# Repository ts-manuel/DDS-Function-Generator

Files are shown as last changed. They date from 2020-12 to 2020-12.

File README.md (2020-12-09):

# DDS Function Generator
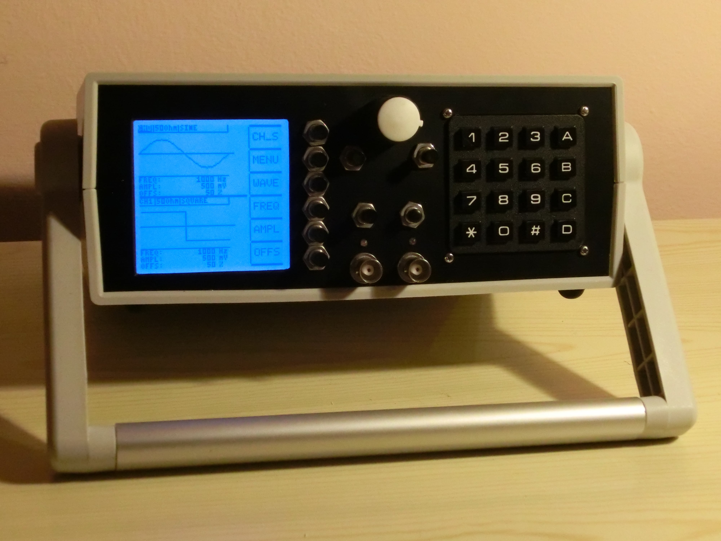
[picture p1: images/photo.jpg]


<!-- TABLE OF CONTENTS -->
<details open="open">
  <summary>Table of Contents</summary>
  <ol>
    <li>
      <a href="#about-the-project">About The Project</a>
    </li>
    <li>
      <a href="#getting-started">Getting Started</a>
      <ul>
        <li><a href="#prerequisites">Prerequisites</a></li>
        <li><a href="#compiling-code-for-the-cpu">Compiling code for the CPU</a></li>
        <li><a href="#how-to-program-the-fpga">How to program the FPGA</a></li>
      </ul>
    </li>
    <li>
        <a href="#theory-of-operation">Theory of Operation</a>
        <ul>
            <li><a href="#block-diagram">Block Diagram</a></li>
            <li><a href="#fpga-internal-structure">FPGA Internal Structure</a></li>
            <li><a href="#dds-core">DDS Core</a></li>
            <li><a href="#wave-generator">Wave Generator</a></li>
        </ul>
    </li>
    <li><a href="#future-improvements">Future Improvements</a></li>
    <li><a href="#references">References</a></li>
    <li><a href="#disclaimer">Disclaimer</a></li>
  </ol>
</details>

<!-- ABOUT THE PROJECT -->
## About The Project
This project is a dual-channel function generator. Waveforms are generated digitally inside an FPGA via DDS ([Direct Digital Synthesis](https://www.analog.com/en/analog-dialogue/articles/all-about-direct-digital-synthesis.html)). The main purpose of this project was to get familiar with FPGAs and at the same time build something useful to have in the lab.

* Frequency DC to 20Mhz
* Power 28 dBm - 6Vrms into 50 Ohms
* Output waveforms: square, triangle, sawtooth, sine, wave file from SD card
* Independent AM and FM modulation on both channels
* Frequency Sweep
* Programmable phase offset between channels

<!-- GETTING STARTED -->
## Getting Started
### Prerequisites
* [Quartus 18.1](https://fpgasoftware.intel.com/18.1/?edition=lite) with `MAX 10 FPGA device support`

### Compiling code for the CPU
* Open Quartus, click on `Tools > Nios II Software Build Tools for Eclipse`
* Select a folder to be used as a workspace (make sure the path has no spaces)
* Click on `File > Import`
* Select `General > Existing Project into Workspace` then click next
* Browse for the folder `fpga/software` select both projects and click finish
* right-click on `DDS_FunctionGen_20Mhz_bsp` than on `Nois II > Generate BSP`
* Now to build the project right-click on `DDS_FunctionGen_20Mhz` than click on `Build Project`
* To generate the FPGA FLASH initialization file, right-click on `DDS_FunctionGen_20Mhz` then click `Make Targets > Build`, select `mem_init_generate` and press `Build`

### How to program the FPGA
* Open the project file `fpga/DDS_FunctionGenerator_20Mhz.qpf` with Quartus
* Press `Compile Design`

<!-- BLOCK DIAGRAM -->
## Theory of Operation
This section gives a basic overview of the main components and how they interact.

### Block Diagram
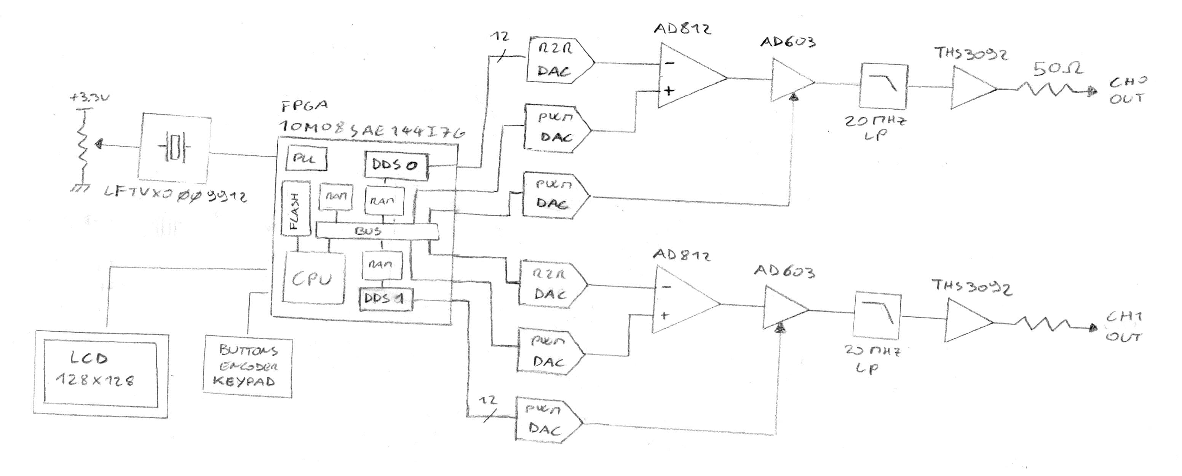
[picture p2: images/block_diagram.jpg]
block diagram

The driver of the show is the FPGA, it's a `10M08SAE144I7G` from the Altera MAX10 Series. MAX10 devices are cool because they have a built-in configuration flash memory and some UFM (User Flash Memory) that can be written when the FPGA is programmed to store non-volatile data. This project uses the UFM to store code for the CPU.\
The clock is provided by a 10Mhz TCXO oscillator, a potentiometer connected to the adj. pin is used to adjust the frequency.\
First, the signal is generated digitally inside the FPGA, then it goes into a 12bit R2R DAC that converts it to an analog voltage. The signal then passes through an inverting op-amp where a DC offset is added. After that, there's a VGA to control the output level. The signal is then filtered by an active op-amp filter before entering the final amplifier.

### FPGA Internal Structure
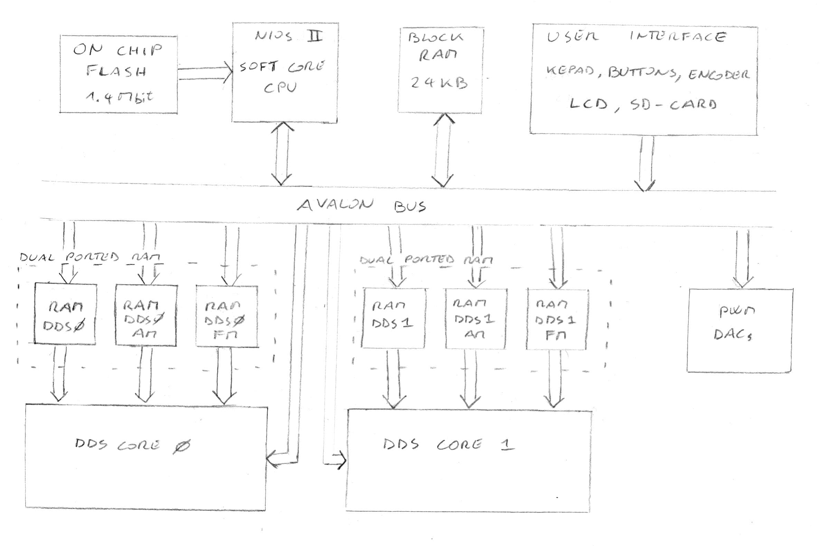
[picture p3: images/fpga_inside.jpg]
FPGA Internal Structure

This block diagram describes the interaction between modules inside the FPGA. All components are memory-mapped on the same bus and are all controlled by the CPU. The CPU is a NIOS II Soft Core provided by Altera, it executes code directly from FLASH. It handles all the user interface stuff like responding to button presses, updating the screen and talking to the SD card.\
The second main module is the DDS Core, there are two of them, one for each channel.
The DDS Core is responsible for the generation of the output waveform. Each DDS Core interfaces whit the CPU through three look-up RAMs and a control bus. Waveform parameters like frequency, modulation depth, etc. are set via the control bus. Waveform shape is controlled by the look-up RAM. The CPU can update the look-up RAM content at any time. When a wave file is played, the CPU loads samples from the SD Card into the proper look-up RAM. The output frequency is set equal to the wave file sample frequency therefore, the DDS Core reads one sample at a time from memory and reconstructs the signal. When half of the samples are consumed an interrupt is triggered and the CPU replaces that half with new data.

### DDS Core
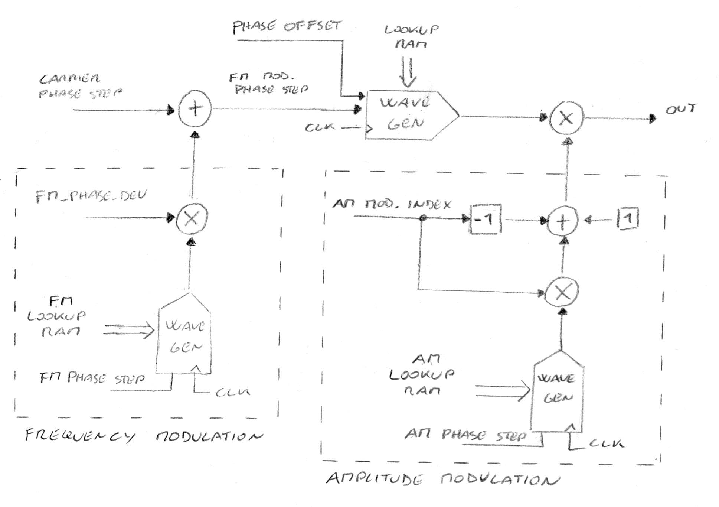
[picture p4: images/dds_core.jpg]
DDS Core

This module is a wrapper around three `Wave Generator` modules. One of them is used to generate the main waveform, the others are for frequency and amplitude modulation. The `CARRIER_PHASE_STEP` input is the frequency of the unmodulated waveform, a signal is added to it to achieve frequency modulation. Amplitude modulation is applied to the signal at the end.

### Wave Generator
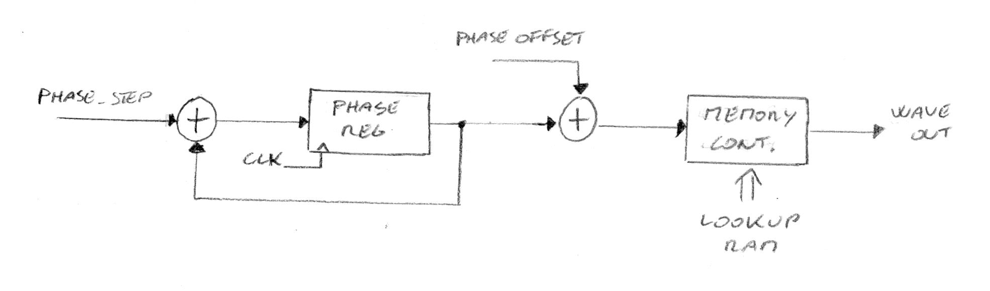
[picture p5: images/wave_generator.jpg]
Wave Generator

This module takes samples from a look-up RAM and outputs a waveform. Frequency is selected with the `PHASE_STEP` input. The `PHASE_OFFSET` input adds a phase offset to the waveform. The memory controller looks at the current phase to generate the appropriate address to index the look-up RAM.

<!-- FUTURE IMPROVEMENTS -->
## Future Improvements
* Add a cache memory between CPU and FLASH. Without that code runs slow and the user interface is not super responsive.
* Upgrade to a bigger FPGA with more UFM. UFM is too small to fit any more code, thus the SD card functions can't be fully implemented.
* Use a proper DAC IC. The R2R DACs are inadequate, even with 0.1% resistors the nonlinearity is too much.

<!-- REFERENCES -->
## References
* [FatFs - Generic FAT Filesystem Module](http://elm-chan.org/fsw/ff/00index_e.html)
* [All About Direct Digital Synthesis - Analog Devices](https://www.analog.com/en/analog-dialogue/articles/all-about-direct-digital-synthesis.html)
* [Fundamentals of Direct Digital Synthesis (DDS) - Analog Devices](https://www.analog.com/media/en/training-seminars/tutorials/MT-085.pdf)

<!-- DISCLAIMER -->
## Disclaimer
The following project is shared "as is", with the sole objective of being useful. The creator of the described piece of hardware and its associated software cannot guarantee its correct functioning under any circumstance. The author of this project will not be held responsible for any material, personal or economic losses to you or any third parties that may arise from using this design. This project will not be used under any circumstances on systems whose responsibility is critical, or from which people's lives depend upon, directly or indirectly.

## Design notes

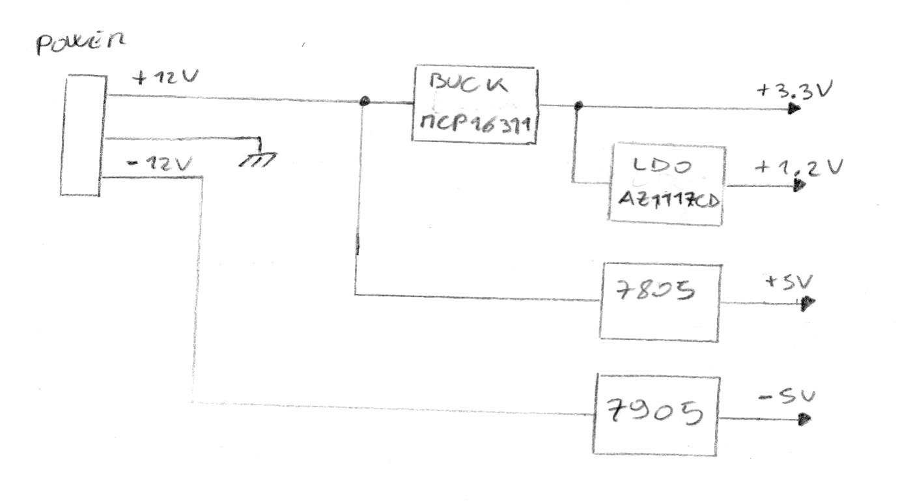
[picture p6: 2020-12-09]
images/power.jpg

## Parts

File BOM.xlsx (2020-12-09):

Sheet: BOM_PartType-FPGA_SignalGenerat
Quantity | Comment | Description | Designator | Footprint | Value |  | Resistance | Capacitance
18 | Vishay 74-293D106X0035C2TE3 | 293D Series 10 uF ±20 % 35 V Surface Mount Standard Molded Tantalum Capacitor | C1, C2, C3, C25, C26, C27, C49, C61, C62, C63, C67,C69, C72, C80, C81, C93, C94, C105 | PCB-uo7hy2lsxdj8f9kxxyxw-1 |  | OK |  | 10 µF
73 | KEMET C0805C104K5RACTU | Capacitor, ceramic, 0.1 uF, +/-10% Tol, 50V, X7R, -55/+125C, 0805, Tin Termination, T&R Paper Tape 7in | C4, C5, C6, C7, C8, C9, C10, C11, C12, C14, C16, C18, C19, C20, C21, C22, C23, C24, C28, C29, C30, C31, C32, C33, C34, C35, C36, C38, C40, C42, C43, C44, C45, C46, C47, C48, C66, C68, C70, C73, C74, C75, C76, C77, C78, C79, C82, C83, C84, C85, C86, C87, C88, C89, C90, C91, C92, C95, C96, C97, C98, C99, C100, C101, C102, C103, C104, C106, C107, C108, C109, C110, C117 | Capacitor 0805 |  | OK |  | 100nF
6 | Kemet C0805C101J5GAC7800 | Multilayer Ceramic Capacitors MLCC - SMD/SMT 50volts 100pF C0G 5% | C13, C15, C17, C37, C39, C41 | CAPC2013X88X50ML20T25 |  | OK |  | 100pF
9 | Kemet C0805C105Z4VACTU | 0805/Case Surface Mount/Pkg 1uf 16-Volt Y5v-Temp Multilayer Ceramic Capacitor | C50, C51, C52, C53, C54, C55, C64, C65, C71 | PCB-s8ugi4gyvlk8r34jcx7t-1 |  | OK |  | 1uF
6 | AVX Interconnect / Elco 08055A4R7CAT2A | CAP CER 4.7PF 50V NP0 0805 | C111, C112, C113, C114, C115, C116 | CAPC2013X71X50LL20T25 |  | OK |  | 4.7pF, 4.7pF, 0.68pF, 4.7pF, 4.7pF, 0.68pF
4 | AVX W3A45C473KAT2A | Cap Ceramic Array 1uF 6.3V JB 20% 1206 SMD 4 Capacitor 85°C Blister Plastic T/R | CN1, CN2, CN3, CN4 | PCB-166aiy90vkqaobkxelpm-1 |  | OK |  | 1uF
1 | LED | Surface Mount LED; Size : 2.0X1.2mm (0805); Color: Green; Lens: Water Clear | D1 | AP2012EC |  | OK
1 | Microchip MCP16311-E/MS | MCP16311 Series 30 Vin 1 A 500 kHz Synchronous Buck Switching Regulator - MSOP-8 | IC1 | PCB-bk1d1h6o78f0n1u0od64-1 |  | OK
1 | BUTTONS | Connector Ejector Header 20 Position 2.54mmThrough Hole | J1 | PCB-2yon6ahruktjsjib9q9l-1 |  | OK
1 | LCD 128x128 | FFC / FPC Board Connector, Easy-On 505110 Series, Surface Mount, Receptacle, 30, Bottom, 0.5 mm | J2 | PCB-vghu3xxueitsn32e31p1-1 |  | OK
1 | LCD BackLight | A2001WR-S-2PSMT | J3 | PCB-pe0trybbrqxd1byjn5yf-1 |  | OK
1 | LED_BTN | 2.54mm (0.1") Pitch SIL Vertical PC Tail Pin Header, 6.1mm mating pin height, gold (hi-temp mould), 6 contacts | J4 | PCB-tb5z704sg1unzd01km8p-1 |  | OK
5 | CH0_OUT | RF Connectors / Coaxial Connectors SMA RA JACK PCB 50 OHM AU | J5 | PCB-3770251-1 |  | OK
1 | EXT_IN | 2.54mm (0.1") Pitch SIL Vertical PC Tail Pin Header, 6.1mm mating pin height, gold (hi-temp mould), 6 contacts | J10 | PCB-tb5z704sg1unzd01km8p-1 |  | OK
1 | SD | 2.54mm (0.1") Pitch SIL Vertical PC Tail Pin Header, 6.1mm mating pin height, gold (hi-temp mould), 6 contacts | J11 | PCB-tb5z704sg1unzd01km8p-1 |  | OK
1 | MAX_10 JTAG | CONN HEADER 10POS DL STR GOLD | K3 | IDC-10_M
2 | TX2SA-5V | Relay; E-Mech; High Voltage; DPDT-NO/NC; Cur-Rtg 2A; Ctrl-V 5DC; Vol-Rtg 30DC; 8 Pin | K4, K5 | PCB-q7xszewk9o8qpg6qe5li-1 |  | OK
1 | SRN5040-150M | Inductor Power Semi-Shielded Wirewound 15uH 20% 100KHz 17Q-Factor Ferrite 1.8A 96mOhm DCR 2020 T/R | L1 | PCB-071yzkx74ra7e346920n-1 |  | OK
3 | ON Semiconductor MMBT2222ALT1G | Bipolar (BJT) Single Transistor, General Purpose, NPN, 40 V, 300 MHz, 225 mW, 600 mA, 300 | Q3, Q4, Q5 | PCB-zwf9crilb66v8jey4z70-1 |  | OK
41 | Panasonic ERJ-6ENF2000V | Thick Film Resistors - SMD 0805 200ohms 1% Tol | R1, R2, R4, R6, R8, R11, R14, R15, R19, R22, R24, R26, R29, R32, R33, R37, R38, R46, R48, R52, R53, R55, R57, R59, R62, R65, R66, R70, R73, R75, R77, R80, R83, R84, R88, R89, R97, R99, R108, R109, R110 | RESC2013X70X40ML20T20 |  | OK | 200.0 O
28 | Panasonic ERJ-6ENF1000V | Thick Film Resistors - SMD 0805 100ohms 1% Tol | R3, R5, R7, R9, R12, R16, R20, R25, R27, R30, R34, R54, R56, R58, R60, R63, R67, R71, R76, R78, R81, R85, R114, R115, R116, R117, R124, R125 | RESC2013X70X40NL20T20 |  | OK | 100.0 O, 100.0 O, 100.0 O, 100.0 O, 100.0 O, 100.0 O, 100.0 O, 100.0 O, 100.0 O, 100.0 O, 100.0 O, 100.0 O, 100.0 O, 100.0 O, 100.0 O, 100.0 O, 100.0 O, 100.0 O, 100.0 O, 100.0 O, 100.0 O, 100.0 O, 100O, 100O, 100O, 100O, 100.0 O, 100.0 O
19 | Panasonic ERJ-6GEYJ102V | Res Thick Film 0805 1K Ohm 5% 0.125W(1/8W) ±200ppm/C Molded SMD Automotive Embossed T/R | R10, R13, R17, R18, R31, R39, R42, R44, R45, R61, R64, R68, R82, R90, R93, R96, R106, R118, R121 | RESC2013X70X40ML20T20 |  | OK | 1KO
6 | Panasonic ERJ-6GEYJ301V | Thick Film Resistors - SMD 0805 300ohms 5% Tol | R21, R36, R47, R72, R87, R98 | RESC2013X70X40ML20T20 |  | OK | 300O
2 | Panasonic ERA-6AEB302V | Res Thin Film 0805 3K Ohm 0.1% 0.125W(1/8W) ±25ppm/C Molded SMD Automotive Punched T/R | R23, R51 | RESC2013X60X40LL20T25 |  | OK | 3 kO
9 | Panasonic ERJ-6GEYJ104V | Thick Film Resistors - SMD 0805 100Kohms 5% Tol | R28, R35, R41, R50, R79, R86, R92, R101, R111 | RESC2013X70X40ML20T20 |  | OK | 100KO
16 | Panasonic ERJ-6GEYJ103V | Thick Film Resistors - SMD 0805 10Kohms 5% Tol | R40, R49, R74, R91, R94, R95, R100, R102, R103, R104, R105, R113, R119, R122, R123, R126 | PCB-azsjq85o2tcwginob1hi-1 |  | OK | 10KO
2 | Panasonic ERJ-6GEYJ162V | Thick Film Resistors - SMD 0805 1.6Kohms 5% Tol | R43, R69 | RESC2013X70X40ML20T20 |  | OK | 1.6KO
1 | Panasonic ERJ-6ENF3162V | Thick Film Resistors - SMD 0805 31.6Kohms 1% Tol | R112 | RESC2013X70X40ML20T20 |  | OK | 31.6KO
1 | +/- 5ppm | Res Trimmer 5K Ohm 25% 1/10W 1(Elec)/1(Mech)Turn (3 X 3.8mm) Foot Print SMD Embossed T/R | R120 | PCB-8jk29cqaxlfsylh8eiq4-1 |  | OK
6 | Yageo YC164-JR-071KL | Res Thick Film Array 10K Ohm 5% ??? }200ppm/??? ???????????????????????????????????????????????????????????????????????????????????????????????????????????????????????????????????????????????????????????????????????????????????????????????????????????????????????????????????????????????????????????????????????????????????????????????????????????????????????????????????????????????????????????????????????????????????????????????????????????????????????????????????????????????????????????????????????????????????????????????????????????????????????????????? ISOL Molded 8-Pin 1206(4 X 0603) Convex SMD Paper T/R, Res Thick Film Array 10K Ohm 5% ??? }200ppm/??? ???????????????????????????????????????????????????????????????????????????????????????????????????????????????????????????????????????????????????????????????????????????????????????????????????????????????????????????????????????????????????????????????????????????????????????????????????????????????????????????????????????????????????????????????????????????????????????????????????????????????????????????????????????????????????????????????????????????????????????????????????????????????????????????????? ISOL Molded 8-Pin 1206(4 X 0603) Convex SMD Paper T/R, Res Thick Film Array 10K Ohm 5% ??? }200ppm/??? ??????????????????????????????????????????????????????????????????????????????????????????????????????????????????????????????????????????????????????????????????????????????????????????????????????????????????????????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 | RN1, RN2, RN3, RN4, RN5, RN6 | PCB-jvpnorgmdmak109y2eet-1 |  | OK | 10.0 kO
2 | AD812ARZ | Double Channel Low Power Operational Amplifier, 145 MHz BW, 425 V/us SR, Industrial, 8-pin SOIC (R-8), Tube | U1, U5 | ADI-R-8_M |  | OK
2 | AD603ARZ | Operational amplifier; 90MHz; 4.75÷6.3VDC; Channels: 1; SO8 | U2, U6 | PCB-l9fbcuaq33md29w8sm4k-1 |  | OK
2 | THS3092DDA | Dual-High-Voltage, Low Distortion, Current-Feedback Operational Amplifier, 10 to 30 V, -40 to 85 degC, 8-pin SOP (DDA8), Green (RoHS & no Sb/Br) | U3, U7 | TI-DDA8-1775X1775TP_M |  | OK
2 | LM358ADR2G | Single Supply Dual Operational Amplifier, 3 to 32 V, 0 to 70 degC, 8-Pin SOIC, Pb-Free, Tape and Reel | U4, U8 | ONSC-SOIC-8-751-07_V |  | OK
1 | Altera 10M04SCE144C8G | FPGA MAX 10 Family 4000 Cells 55nm Technology 1.2V 144-Pin EQFP EP | U9 | PCB-s7ga4y0v6jbsxaai8c4a-1 |  | OK
1 | AZ1117CD-1.2TRG1 | AZ1117C Series 800 mA 1.2 V Fixed Output LDO Linear Regulator - TO-252 | U12 | PCB-mun8wuye1ifdmdeb068p-1 |  | OK
1 | MC78M05CDTG | Linear voltage regulator [ON Semiconductor] MC78M05CDTG Linear voltage regulator | U13 | PCBComponent_1 - duplicate |  | OK
1 | MC79M05CDTG | MC79M00 Series 0.5 A 5 V Fixed Output Negative Voltage SMT Regulator -TO-252 | U14 | PCB-wwaj321dsnlyxa6mte0u-1 |  | OK
1 | NCP81071B | MOSFET DRVR 5A 2-OUT Lo Side Non-Inv 8-Pin SOIC T/R | U15 | PCB-6yy49i6oplekkq6w5mds-1 |  | OK
1 | PL133-37TC | PL133-37 Series 1.62 to 3.63 V 150 MHz 1: 3 Fanout Buffer IC - SOT-23-6 | U16 | PCB-n6y2n6l42toizub0nv20-1 |  | OK
1 | CM1216-08MR | 8-Channel Low Capacitance ESD Array, 10-Pin MSOP, Pb-Free, Tape and Reel | U17 | ONSC-MSOP-10-846AE-01_N |  | OK
1 | POWER | TERM BLOCK PCB 3POS 5.0MM GREEN | X1 | PCB-ze6c03jjo3jausbqidy3-1 |  | OK
1 | LFTVXO009912Bulk | 11ppm, 15pF, 10 mhZ Crystal Oscillator | Y1 | PCB-oey7f5uywsj21yxs0bl8-1 |  | OK

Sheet: Foglio1
Quantity | Part Number | Description | Designator | Value
1 | Molex 505110-3091 | FFC / FPC Board Connector, Easy-On 505110 Series, 30, Bottom, 0.5 mm | J2
1 | NHD-C128128BZ-FSW-GBW | LCD 128 x 128
1 | LFTVXO009912Bulk | 11ppm, 15pF, 10 MHz Crystal Oscillator | Y1 | 10 MHz
1 | Kingbright AP2012EC | Surface Mount LED; Size : 2.0X1.2mm (0805); Color: Green; Lens: Water Clear | D1 | RED
1 | Murata 1255AY-150M=P3 | Inductor 15uH 20% 100KHz 17Q-Factor Ferrite 1.8A 96mOhm DCR 2020 T/R | L1 | 15 uH
2 | TX2SA-5V | Relay; DPDT-NO/NC; Cur-Rtg 2A; Ctrl-V 5DC; Vol-Rtg 30DC; 8 Pin | K4, K5
1 | IP-6131 | Enclosures, Boxes & Cases 6.52 x 8.85 x 3.54
CAPACITORS
18 | Vishay 74-293D106X0035C2TE3 | 10 uF ±20 % 35 V Surface Mount Standard Molded Tantalum Capacitor | C1, C2, C3, C25, C26, C27, C49, C61, C62, C63, C67,C69, C72, C80, C81, C93, C94, C105 | 10 uF
9 | Kemet C0805C105Z4VACTU | 0805/Case 1uf 16-Volt Y5v-Temp Multilayer Ceramic Capacitor | C50, C51, C52, C53, C54, C55, C64, C65, C71 | 1 uF
4 | AVX W3A45C473KAT2A | Cap Ceramic Array 1uF 6.3V JB 20% 1206 SMD 4 Capacitor | CN1, CN2, CN3, CN4 | 1 uF
73 | KEMET C0805C104K5RACTU | Capacitor, ceramic, 0.1 uF, +/-10% Tol, 50V, X7R, -55/+125C, 0805 | C4, C5, C6, C7, C8, C9, C10, C11, C12, C14, C16, C18, C19, C20, C21, C22, C23, C24, C28, C29, C30, C31, C32, C33, C34, C35, C36, C38, C40, C42, C43, C44, C45, C46, C47, C48, C66, C68, C70, C73, C74, C75, C76, C77, C78, C79, C82, C83, C84, C85, C86, C87, C88, C89, C90, C91, C92, C95, C96, C97, C98, C99, C100, C101, C102, C103, C104, C106, C107, C108, C109, C110, C117 | 100 nF
6 | Kemet C0805C101J5GAC7800 | Multilayer Ceramic Capacitors MLCC - SMD/SMT 50volts 100pF C0G 5% | C13, C15, C17, C37, C39, C41 | 100 pF
4 | Vishay VJ0805A4R7BXACW1BC | CAP CER 4.7PF 50V NP0 0805 +-0.1pF | C111, C112, C114, C115 | 4.7 pF
2 | AVX 08055AR68CAT2A | CAP CER 0.68PF 50V NP0 0805 | C113, C116 | 0.68 pF
RESISTORS
9 | Panasonic ERJ-6GEYJ104V | Thick Film Resistors - SMD 0805 100Kohms 5% Tol | R28, R35, R41, R50, R79, R86, R92, R101, R111 | 100 KΩ
1 | Panasonic ERJ-6ENF3162V | Thick Film Resistors - SMD 0805 31.6Kohms 1% Tol | R112 | 31.6 KΩ
6 | Yageo YC164-JR-071KL | Res Thick Film Array 10K Ohm 5% 200ppm | RN1, RN2, RN3, RN4, RN5, RN6 | 10 KΩ
16 | Panasonic ERJ-6GEYJ103V | Thick Film Resistors - SMD 0805 10Kohms 5% Tol | R40, R49, R74, R91, R94, R95, R100, R102, R103, R104, R105, R113, R119, R122, R123, R126 | 10 KΩ
1 | Bourns TC33X-2-502G | Res Trimmer 5K Ohm 25% 1/10W | R120 | 5 KΩ
2 | Yageo RC0805FR-073KL | Res Thin Film 0805 3K Ohm 0.1% 0.125W(1/8W) ±25ppm | R23, R51 | 3 KΩ
2 | Yageo ERJ-6GEYJ162V | Thick Film Resistors - SMD 0805 1.6Kohms 5% Tol | R43, R69 | 1.6 KΩ
19 | Panasonic CRCW08051K00JNEA | Res Thick Film 0805 1K Ohm 5% 0.125W(1/8W) ±200ppm | R10, R13, R17, R18, R31, R39, R42, R44, R45, R61, R64, R68, R82, R90, R93, R96, R106, R118, R121 | 1 KΩ
6 | Panasonic ERJ-6GEYJ301V | Thick Film Resistors - SMD 0805 300ohms 5% Tol | R21, R36, R47, R72, R87, R98 | 300 Ω
42 | Panasonic ERJ-6ENF2000V | Thick Film Resistors - SMD 0805 200ohms 1% Tol | R1, R2, R4, R6, R8, R11, R14, R15, R19, R22, R24, R26, R29, R32, R33, R37, R38, R46, R48, R52, R53, R55, R57, R59, R62, R65, R66, R70, R73, R75, R77, R80, R83, R84, R88, R89, R97, R99, R108, R109, R110 | 200 Ω
28 | Yageo RT0805FRE07100RL | Thick Film Resistors - SMD 0805 100ohms 1% Tol | R3, R5, R7, R9, R12, R16, R20, R25, R27, R30, R34, R54, R56, R58, R60, R63, R67, R71, R76, R78, R81, R85, R114, R115, R116, R117, R124, R125 | 100 Ω
TRANSISTORS / LINEAR REGULATORS
3 | MMBT2222ALT1G | Bipolar (BJT) Single Transistor, General Purpose, NPN, 40 V, 600 mA | Q3, Q4, Q5 | NPN
1 | AZ1117CD-1.2TRG1 | AZ1117C Series 800 mA 1.2 V Fixed Output LDO Linear Regulator - TO-252 | U12 | 1.2V
1 | MC78M05CDTG | Linear voltage regulator [ON Semiconductor] MC78M05CDTG | U13 | +5V
1 | MC79M05CDTG | 0.5 A 5 V Fixed Output Negative Voltage SMT Regulator -TO-252 | U14 | -5V
INTEGRATED CIRCUITS
2 | AD812ARZ | Double Channel Operational Amplifier, 145 MHz BW, 425 V/us, 8-pin SOIC | U1, U5
2 | LM358ADR2G | Single Supply Dual Operational Amplifier, 3 to 32 V, 0 to 70 degC, 8-Pin SOIC | U4, U8
2 | AD603ARZ | Operational amplifier; 90MHz; 4.75÷6.3VDC; Channels: 1; SO8 | U2, U6
2 | THS3092DDA | Dual-High-Voltage, Current-Feedback Operational Amplifier, 10 to 30 V | U3, U7
1 | NCP81071B | MOSFET DRVR 5A 2-OUT Lo Side Non-Inv 8-Pin SOIC T/R | U15
1 | Microchip MCP16311-E/MS | 30 Vin 1 A 500 kHz Synchronous Buck Switching Regulator - MSOP-8 | IC1 | 3.3V
1 | Altera 10M08SAE144I7G | FPGA MAX 10 Family 8000 Cells 55nm Technology 1.2V 144-Pin EQFP EP | U9
1 | Microchip PL133-37TC | PL133-37 Series 1.62 to 3.63 V 150 MHz 1: 3 Fanout Buffer IC - SOT-23-6 | U16
1 | CM1216-08MR | 8-Channel Low Capacitance ESD Array, 10-Pin MSOP, Pb-Free, Tape and Reel | U17

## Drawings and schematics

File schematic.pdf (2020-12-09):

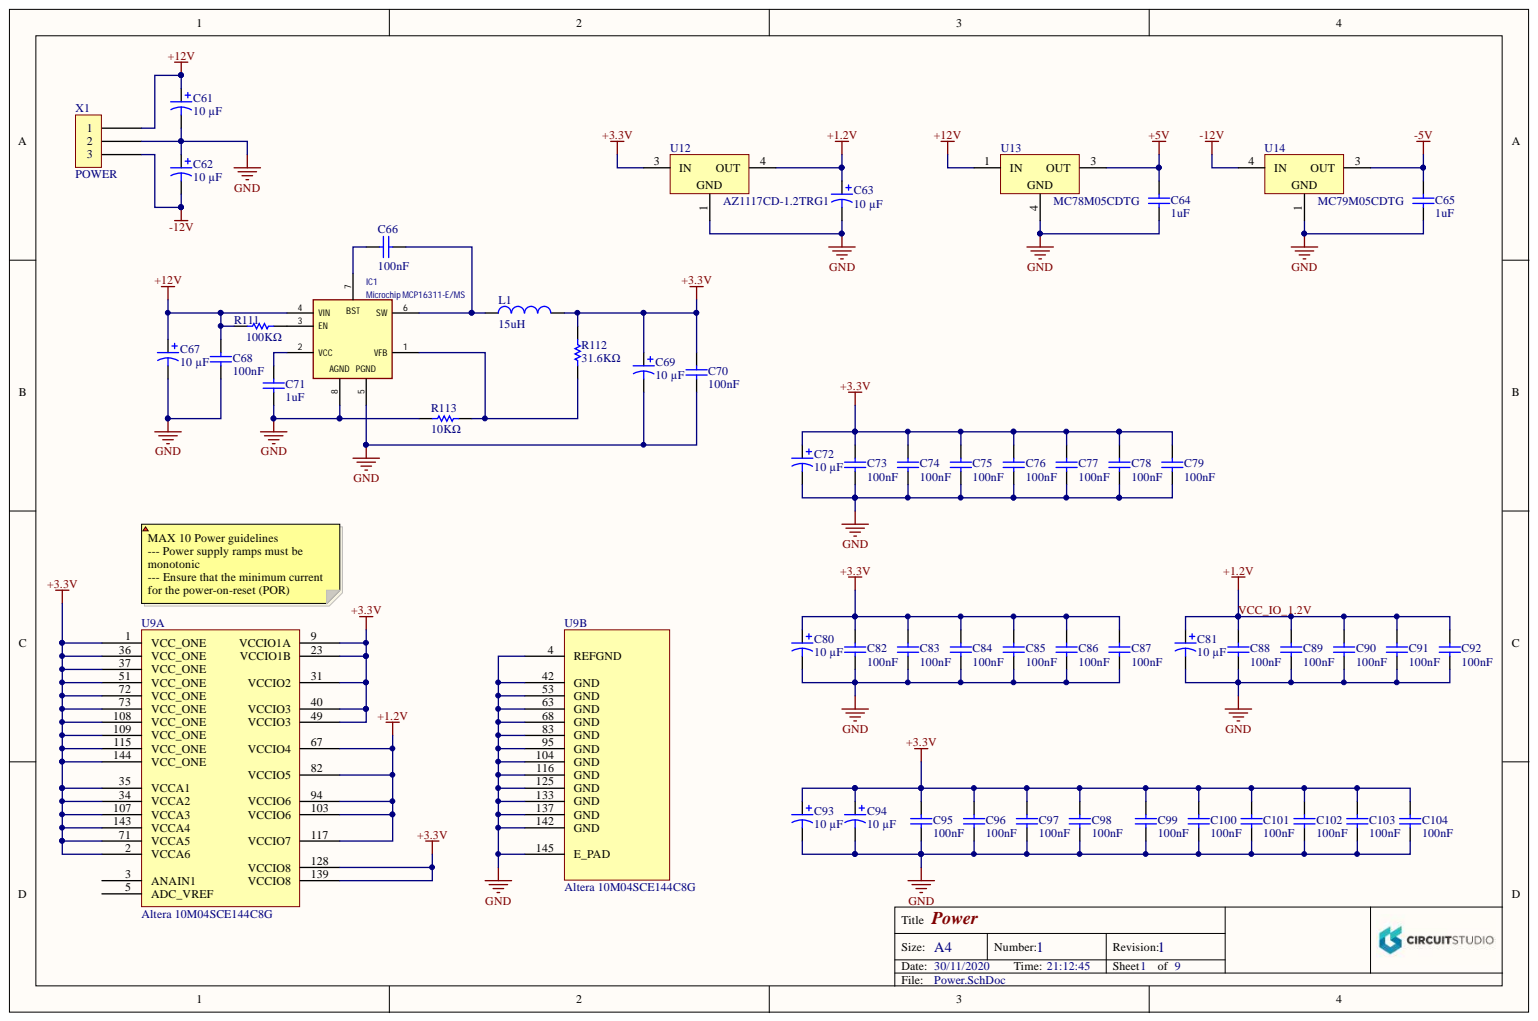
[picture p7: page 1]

MAX 10 Power guidelines
--- Power supply ramps must be
monotonic
--- Ensure that the minimum current
for the power-on-reset (POR)

Power Title

A4 Size: | 1 Number: | 1 Revision:
Date: 30/11/2020 Time: 21:12:45 | | Sheet of

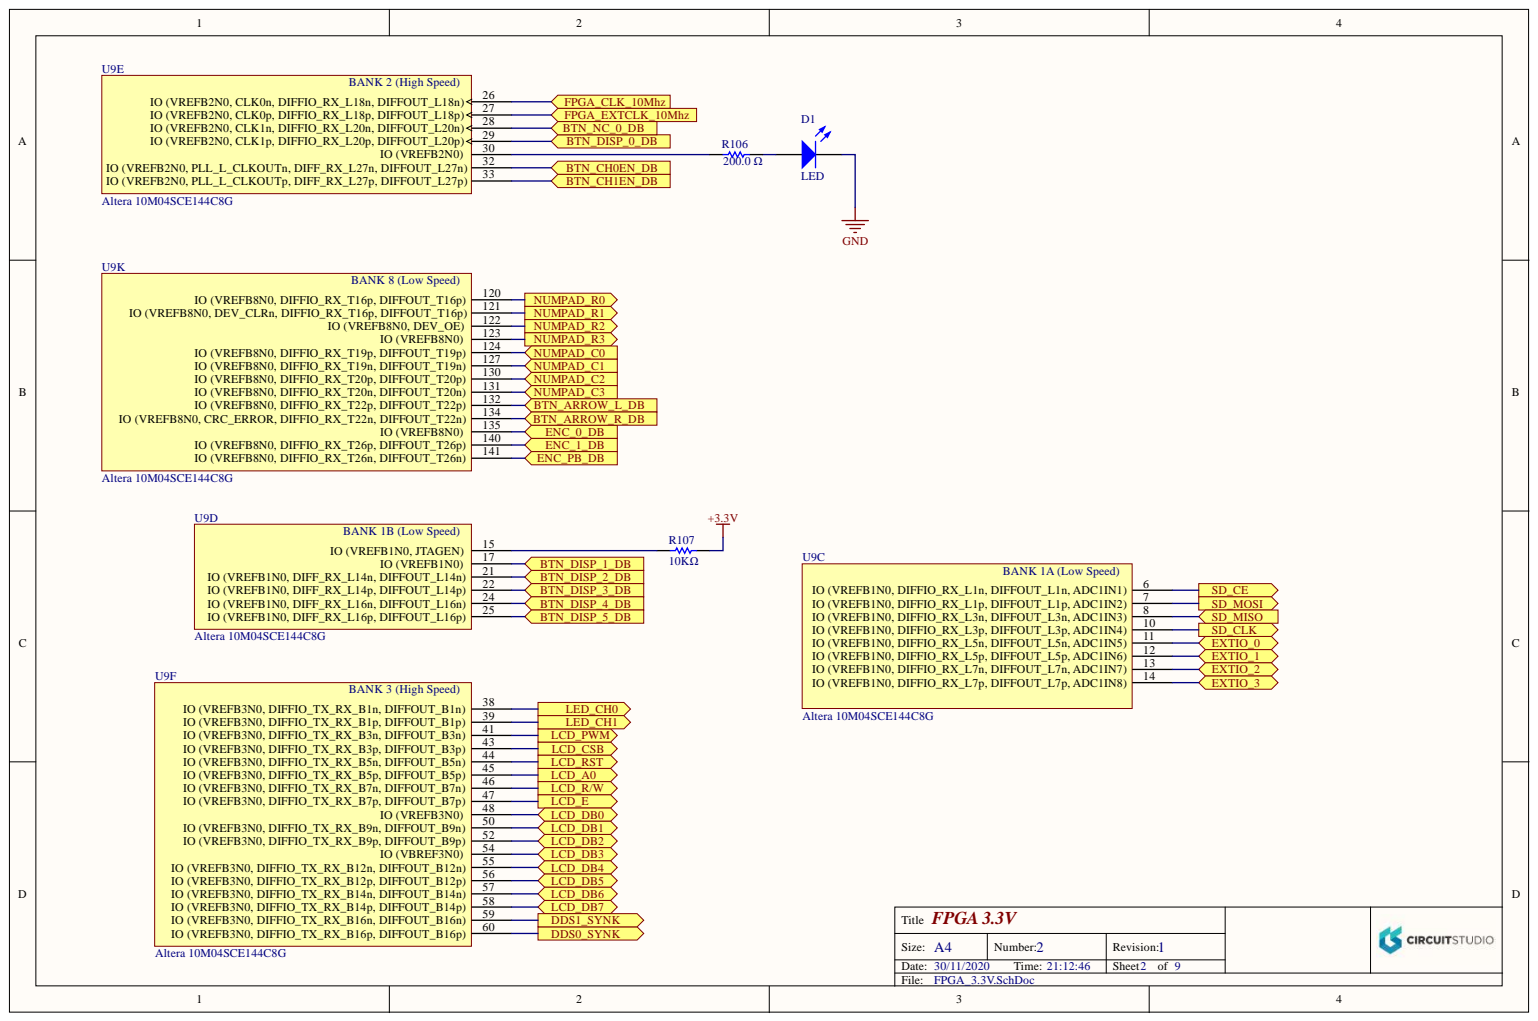
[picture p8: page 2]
IO (VREFB2N0, CLK0n, DIFFIO_RX_L18n, DIFFOUT_L18n); IO (VREFB2N0, CLK0p, DIFFIO_RX_L18p, DIFFOUT_L18p); IO (VREFB2N0, CLK1n, DIFFIO_RX_L20n, DIFFOUT_L20n); IO (VREFB2N0, CLK1p, DIFFIO_RX_L20p, DIFFOUT_L20p); IO (VREFB2N0); IO (VREFB2N0, PLL_L_CLKOUTn, DIFF_RX_L27n, DIFFOUT_L27n); IO (VREFB2N0, PLL_L_CLKOUTp, DIFF_RX_L27p, DIFFOUT_L27p); Altera 10M04SCE144C8G; IO (VREFB8N0, DIFFIO_RX_T16p, DIFFOUT_T16p); IO (VREFB8N0, DEV_CLRn, DIFFIO_RX_T16p, DIFFOUT_T16p)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

BANK 2 (High Speed)

BANK 8 (Low Speed)

BANK 1B (Low Speed)

BANK 1A (Low Speed)

BANK 3 (High Speed)

FPGA 3.3V Title

A4 Size: | 2 Number: | 1 Revision:

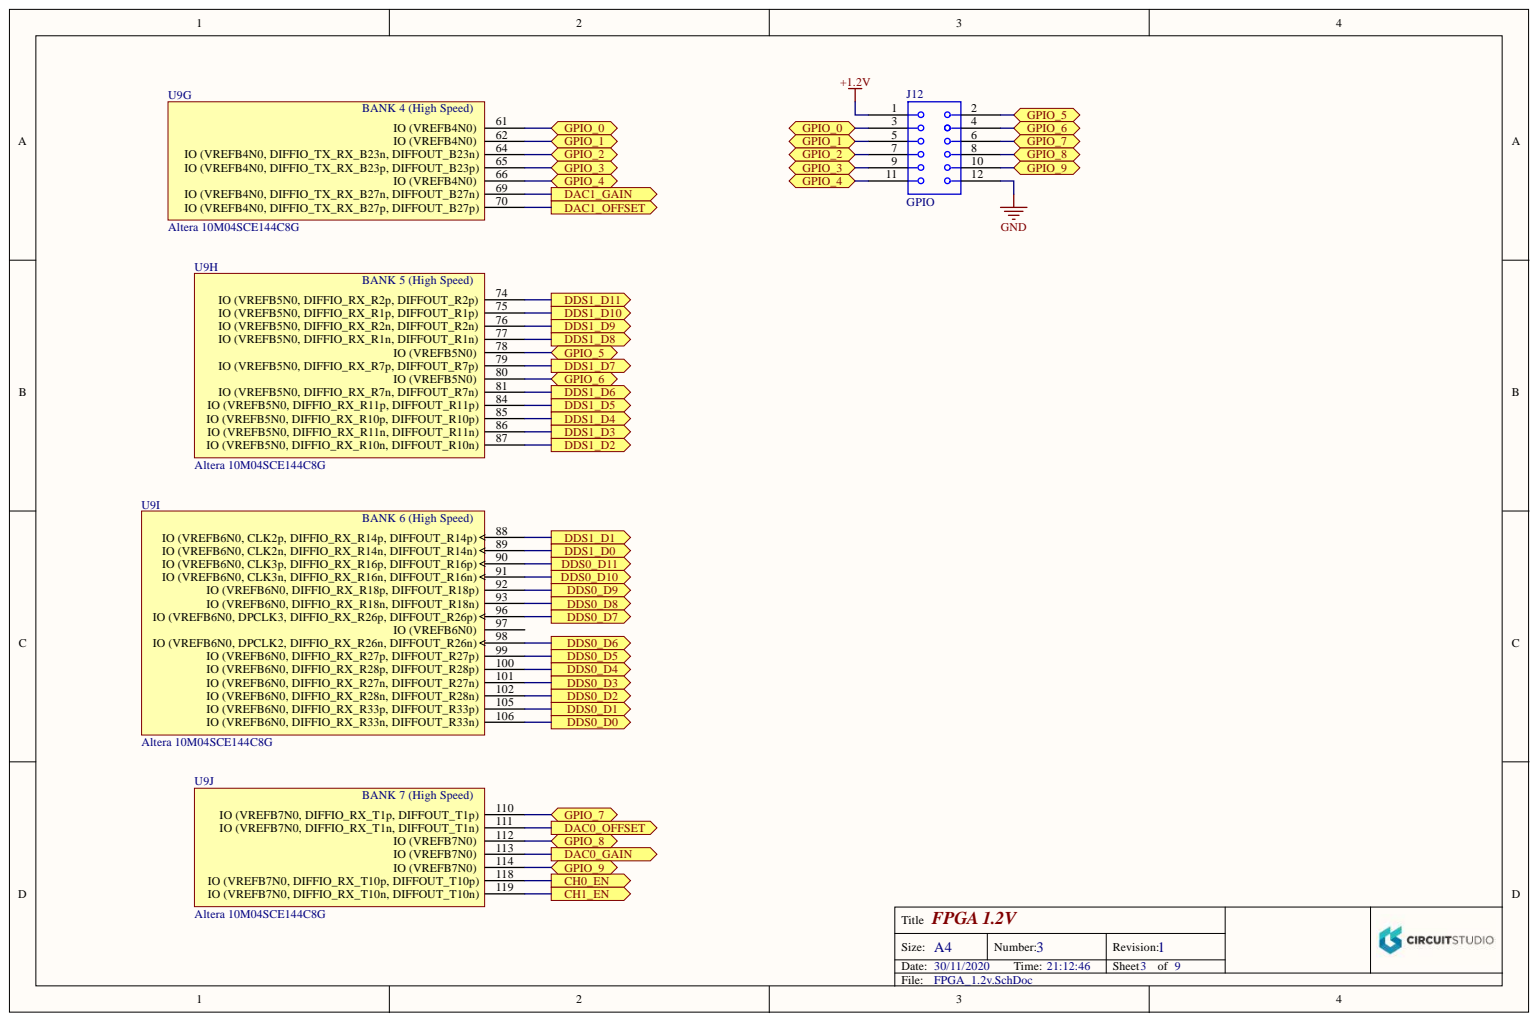
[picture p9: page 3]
IO (VREFB4N0); IO (VREFB4N0, DIFFIO_TX_RX_B23n, DIFFOUT_B23n); IO (VREFB4N0, DIFFIO_TX_RX_B23p, DIFFOUT_B23p); IO (VREFB4N0, DIFFIO_TX_RX_B27n, DIFFOUT_B27n); IO (VREFB4N0, DIFFIO_TX_RX_B27p, DIFFOUT_B27p); Altera 10M04SCE144C8G; IO (VREFB5N0, DIFFIO_RX_R2p, DIFFOUT_R2p); IO (VREFB5N0, DIFFIO_RX_R1p, DIFFOUT_R1p); IO (VREFB5N0, DIFFIO_RX_R2n, DIFFOUT_R2n); IO (VREFB5N0, DIFFIO_RX_R1n, DIFFOUT_R1n); IO (VREFB5N0, DIFFIO_RX_R7p, DIFFOUT_R7p); IO (VREFB5N0, DIFFIO_RX_R7n, DIFFOUT_R7n)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

BANK 4 (High Speed)

BANK 5 (High Speed)

BANK 6 (High Speed)

BANK 7 (High Speed)

FPGA 1.2V Title

A4 Size: | 3 Number: | 1 Revision:

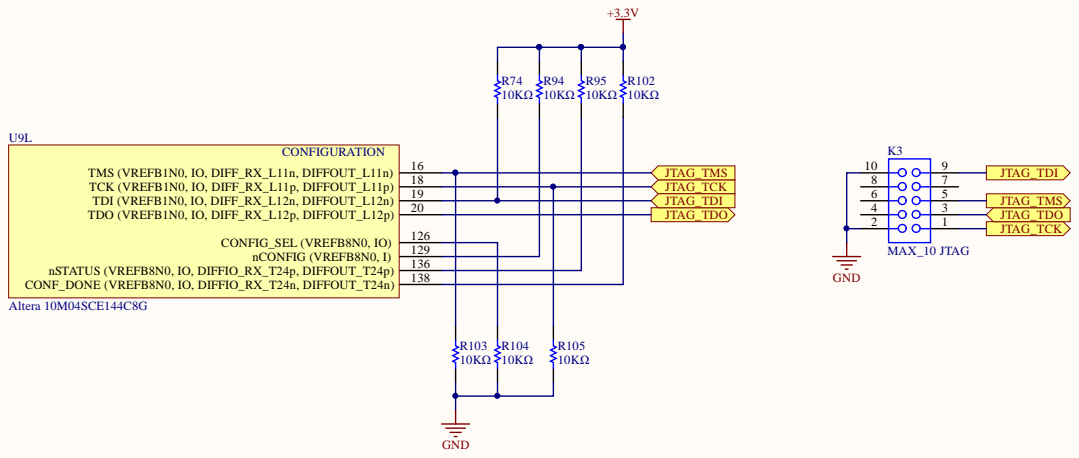
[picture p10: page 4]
US (VREFB8; 0, IO, DIFFIO; p, DIFFO; E (VREFB8; n, DIFFO; L (VREFB8; NFIG (VREFB8; TMS (VREFB1; 0, IO, DIFF_RX; TCK (VREFB1; DI (VREFB1; O (VREFB1; tera 1

1 2 9
1 3 6
1 3 8

FPGA J TAG T i t l e

A4 Size: | 4 N umber: | 1 Rev i s i o n :

/ / T ime: : : | | Sheet o f

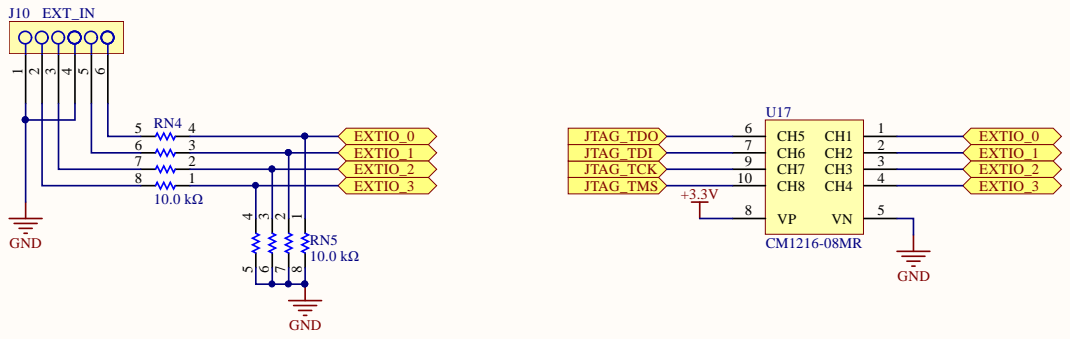
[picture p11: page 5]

Analog T i t l e

A4 Size: | 5 N umber: | 1 Rev i s i o n :

/ / T ime: : : | | Sheet o f

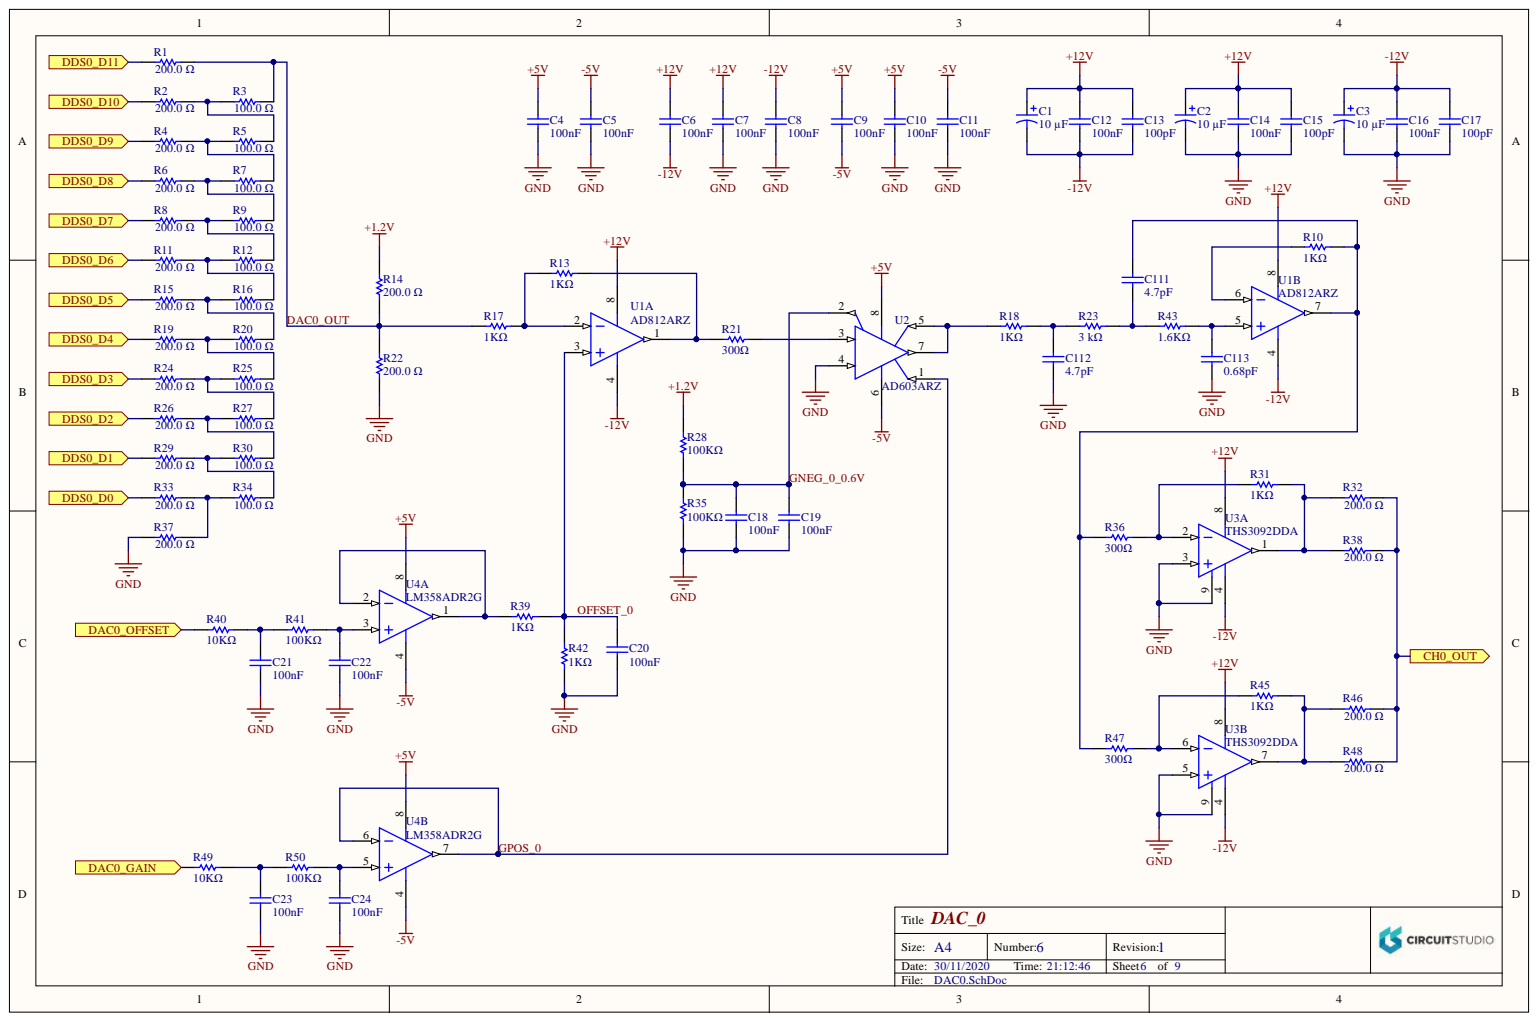
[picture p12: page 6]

DAC_0 Title

A4 Size: | 6 Number: | 1 Revision:

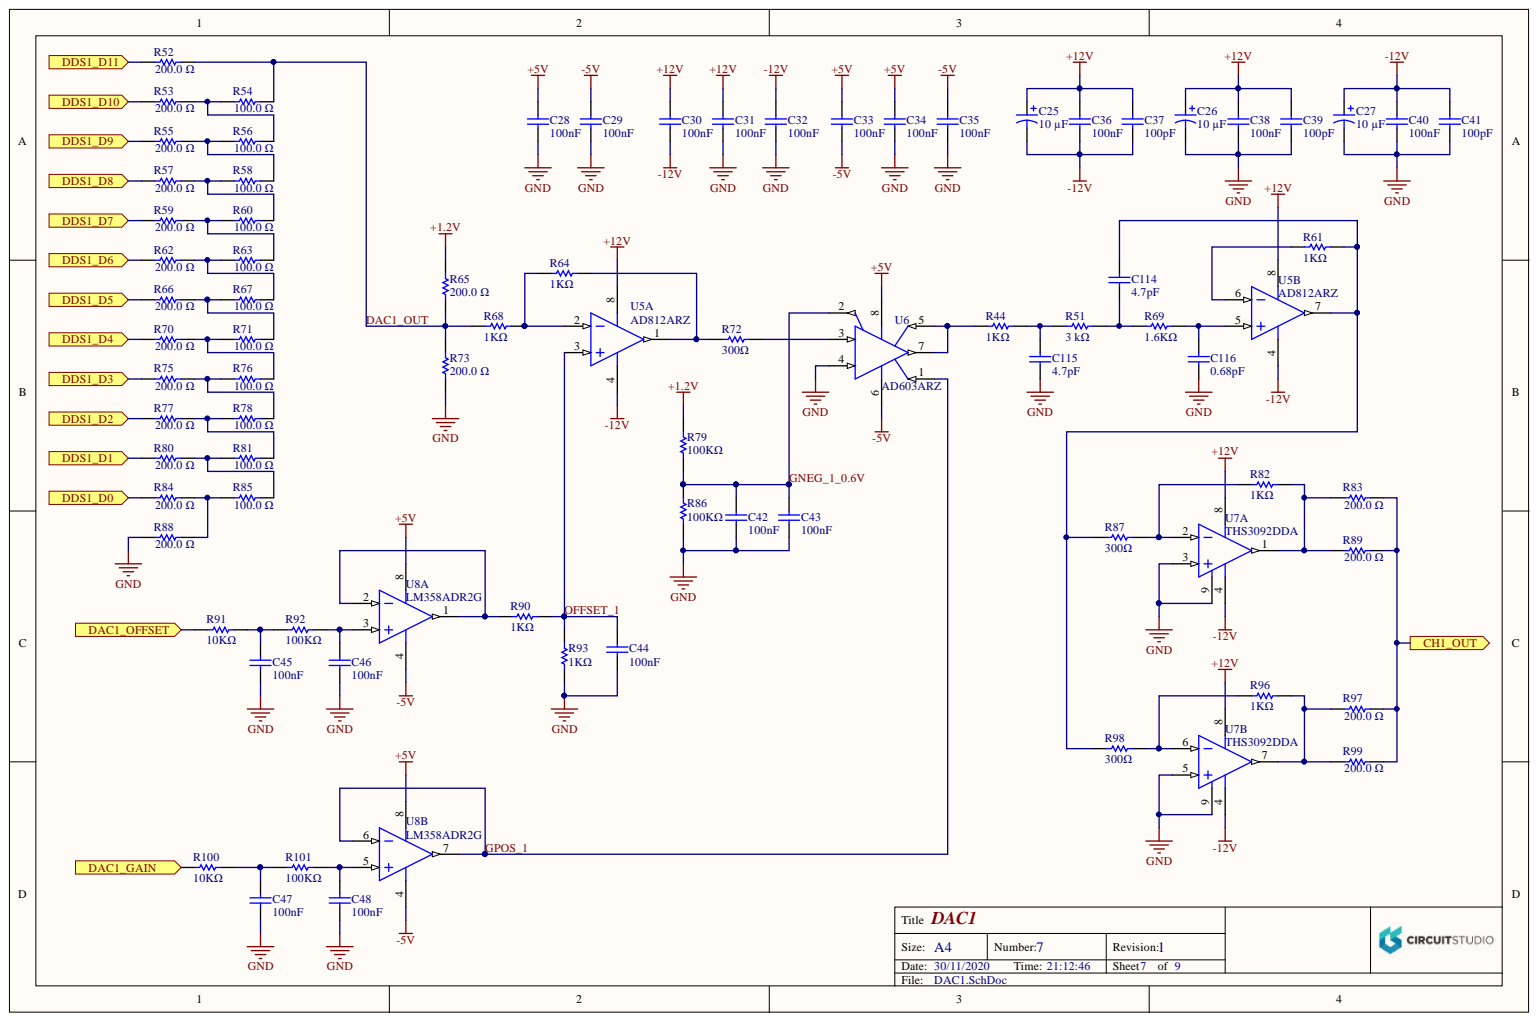
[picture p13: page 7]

DAC1 Title

A4 Size: | 7 Number: | 1 Revision:

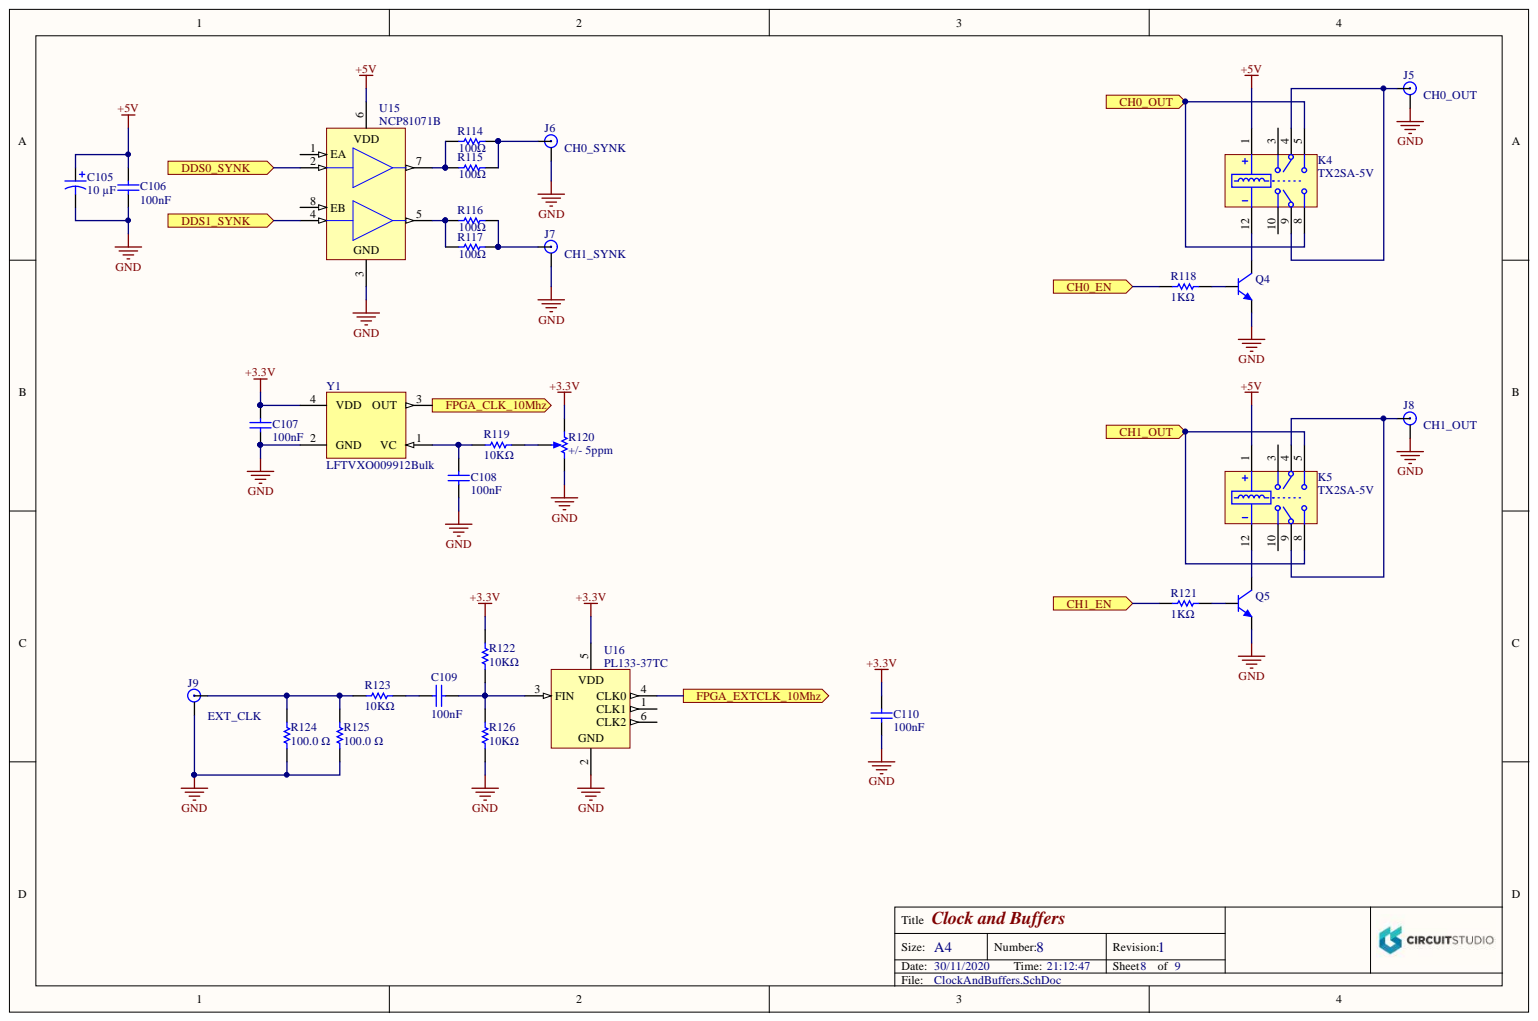
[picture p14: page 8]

Clock and Buffers 8

A4 Size: | N umber: | 1 Rev i s i o n :

/ / T ime: : : | | Sheet o f

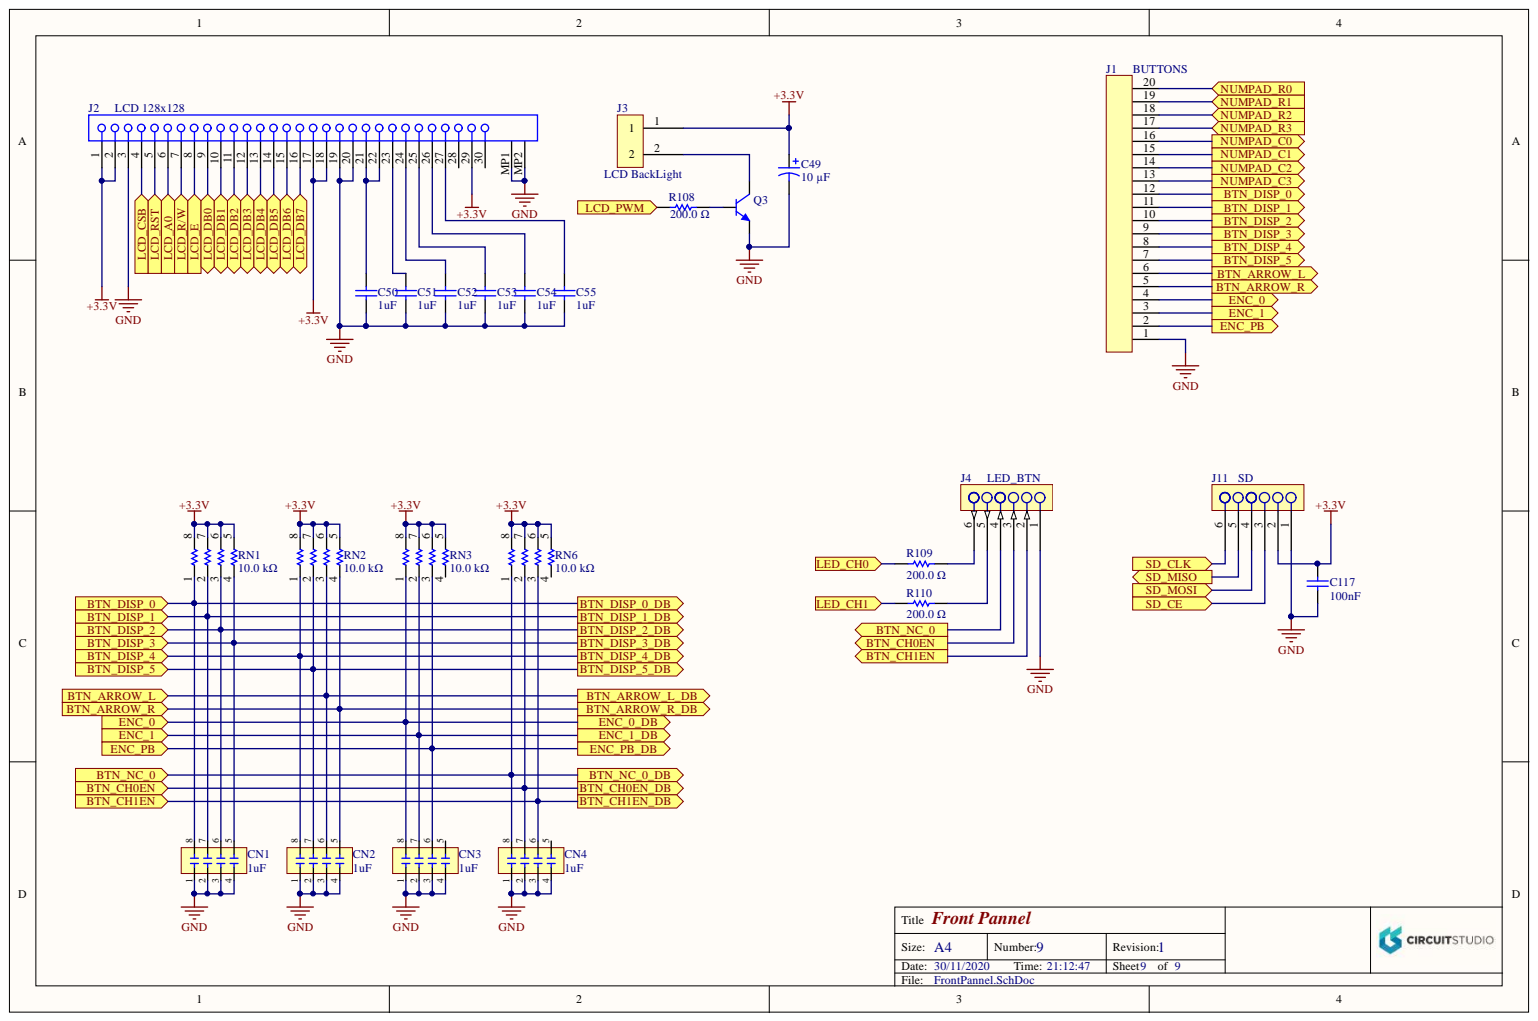
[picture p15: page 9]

Front Pannel Title

A4 Size: | 9 Number: | 1 Revision:

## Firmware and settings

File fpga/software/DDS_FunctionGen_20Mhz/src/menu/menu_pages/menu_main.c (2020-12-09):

/*
 * manu_main.c
 *
 *  Created on: 07 dic 2017
 *      Author: Manuel
 */

#include "common.h"
#include "../menu.h"
#include "../graphics/graphics.h"
#include "../../lcd/GLCD.h"
#include "../../delay/delay.h"
#include "../../hardware/hardware.h"
#include "../../definitions.h"
#include "../../data_structures/dataStructures.h"
#include "../../common_functions/commonFunctions.h"
#include <stdbool.h>
#include <stdio.h>
#include <math.h>

//Function declaration
static void init();
static void draw();
static void btn_display(uint8_t btnDisplay);
static void btn_encoder(uint8_t btnEncoder, int8_t encoder);
static void btn_keypad(uint8_t KeyPressed);

static void DrawCH0();
static void DrawCH1();

//Struttura che descrive una pagina del menu
const s_MenuPage menu_main = {&init, &draw, &btn_display, &btn_encoder, &btn_keypad, false, NULL};

typedef enum {e_PARAMETER_NONE = 0, e_PARAMETER_FREQUENCY = 3, e_PARAMETER_AMPLITUDE = 4, e_PARAMETER_DC_OFFSET = 5} e_SelectedParameter;
static e_SelectedParameter selectedParameter;

static void init(){
	selectedParameter = e_PARAMETER_NONE;
	GP_ResetTypingScreen(NULL, false, false);
}

//Rendering del menu
static void draw(){
//unsigned int StartTime = readTimer_us();

	GLCD_ClrScr();
//printf("GLCD_ClrScr(): %d \n", GetTimeElapsed_us(StartTime));
//StartTime = readTimer_us();
	GLCD_SetFont(TinyFont);
//printf("GLCD_SetFont(): %d \n", GetTimeElapsed_us(StartTime));
//StartTime = readTimer_us();

	DrawCH0();
//printf("DrawCH0(): %d \n", GetTimeElapsed_us(StartTime));
//StartTime = readTimer_us();

	GLCD_HLine(0, _LCD_HALF_H - 1,	_LCD_WIDTH - 32, true);
	GLCD_HLine(0, _LCD_HALF_H,		_LCD_WIDTH - 32, true);
//printf("GLCD_HLine() * 2: %d \n", GetTimeElapsed_us(StartTime));
//StartTime = readTimer_us();

	DrawCH1();
//printf("DrawCH1(): %d \n", GetTimeElapsed_us(StartTime));
//StartTime = readTimer_us();

	//Lateral Buttons
	u_ButtonNames buttons[6] = {{"CH_S"}, {"MENU"}, {"WAVE"}, {"FREQ"}, {"AMPL"}, {"OFFS"}};
	int selectedButton = (selectedParameter != e_PARAMETER_NONE) ? (int)selectedParameter : -1;
	GP_DrawLateralButtons(buttons, selectedButton);
//printf("GP_DrawLateralButtons(): %d \n", GetTimeElapsed_us(StartTime));
//StartTime = readTimer_us();

	//Draw typing screen
	GP_DrawTypingScreen();
//printf("GP_DrawTypingScreen(): %d \n", GetTimeElapsed_us(StartTime));
//StartTime = readTimer_us();

	//Update the lcd
	GLCD_Update();
//printf("GLCD_Update(): %d \n\n", GetTimeElapsed_us(StartTime));
}

static void DrawCH0(){
	const unsigned int chSel = menuVariables.selectedChannel;

	//Top row Text and graphics
	GLCD_SetTextModeInverted(menuVariables.selectedChannel == 0);
	GLCD_PrintString(0, 0, 	"CH0");
	GLCD_SetTextModeInverted(false);
	GLCD_PrintString(15, 0, DDS_Variables[0].OutputEmpedance.array[DDS_Variables[0].OutputEmpedance.selected]);
	GLCD_PrintString(37, 0, str_WaveNames[(int)DDS_Variables[0].WaveType]);
	GLCD_VLine(13, 0, 6, true);
	GLCD_VLine(35, 0, 6, true);
	GLCD_VLine(79, 0, 6, true);
	GLCD_HLine(0, 6, 80, true);

	GP_DrawWave(0, DDS_Variables[0].WaveType, DDS_Variables[0].DCOffset.floatValue);

	//Bottom Text (Freq, Ampl, Offs)
	PrintEditableValueWithSelectedDigit(0, _LCD_HALF_H - 18, 35, "FREQ:", &DDS_Variables[0].Frequency, (chSel == 0 && selectedParameter == e_PARAMETER_FREQUENCY));
	PrintEditableValueWithSelectedDigit(0, _LCD_HALF_H - 12, 35, "AMPL:", &DDS_Variables[0].Amplitude, (chSel == 0 && selectedParameter == e_PARAMETER_AMPLITUDE));
	PrintEditableValueWithSelectedDigit(0, _LCD_HALF_H -  6, 35, "OFFS:", &DDS_Variables[0].DCOffset,  (chSel == 0 && selectedParameter == e_PARAMETER_DC_OFFSET));
	GLCD_HLine(0, 		_LCD_HALF_H - 19, 	80, true);
}

static void DrawCH1(){
	const unsigned int chSel = menuVariables.selectedChannel;

	//Top row Text and graphics
	GLCD_SetTextModeInverted(menuVariables.selectedChannel  == 1);
	GLCD_PrintString(0,		_LCD_HALF_H + 1, "CH1");
	GLCD_SetTextModeInverted(false);
	GLCD_PrintString(15,	_LCD_HALF_H + 1, DDS_Variables[1].OutputEmpedance.array[DDS_Variables[1].OutputEmpedance.selected]);
	GLCD_PrintString(37,	_LCD_HALF_H + 1, str_WaveNames[(int)DDS_Variables[1].WaveType]);
	GLCD_VLine(13, 	_LCD_HALF_H + 1, 6, true);
	GLCD_VLine(35, 	_LCD_HALF_H + 1, 6, true);
	GLCD_VLine(79, 	_LCD_HALF_H + 1, 6, true);
	GLCD_HLine(0, 	_LCD_HALF_H + 7, 80, true);

	GP_DrawWave(_LCD_HALF_H + 1, DDS_Variables[1].WaveType, DDS_Variables[1].DCOffset.floatValue);

	//Bottom Text (Freq, Ampl, Offs)
	PrintEditableValueWithSelectedDigit(0, _LCD_HEIGHT - 17, 35, "FREQ:", &DDS_Variables[1].Frequency, (chSel == 1 && selectedParameter == e_PARAMETER_FREQUENCY));
	PrintEditableValueWithSelectedDigit(0, _LCD_HEIGHT - 11, 35, "AMPL:", &DDS_Variables[1].Amplitude, (chSel == 1 && selectedParameter == e_PARAMETER_AMPLITUDE));
	PrintEditableValueWithSelectedDigit(0, _LCD_HEIGHT -  5, 35, "OFFS:", &DDS_Variables[1].DCOffset,  (chSel == 1 && selectedParameter == e_PARAMETER_DC_OFFSET));
	GLCD_HLine(0, 		_LCD_HEIGHT - 18, 	80, true);
}

//-------------------------- Input Processing ------------------------------------------
static void btn_display(uint8_t btnDisplay){
	switch(btnDisplay){
	case _BTN_DISPLAY_0:	//CHANNEL SELECT
		menuVariables.selectedChannel  = (menuVariables.selectedChannel  + 1) % _NUM_DDS_CHANNELS;
		selectedParameter = e_PARAMETER_NONE;
		GP_ResetTypingScreen(NULL, false, false);
		break;
	case _BTN_DISPLAY_1:	//MENU
		//menu_PushPage(&menu_menu);
		menu_PushPage(&menu_graphicMenu);
		selectedParameter = e_PARAMETER_NONE;
		GP_ResetTypingScreen(NULL, false, false);
		break;
	case _BTN_DISPLAY_2:	//WAVE
		DDS_Variables[menuVariables.selectedChannel].WaveType = (DDS_Variables[menuVariables.selectedChannel ].WaveType + 1) % (_NUM_WAVES - 1);
		break;
	case _BTN_DISPLAY_3:	//FREQUENCY
		selectedParameter = e_PARAMETER_FREQUENCY;
		GP_ResetTypingScreen(&DDS_Variables[menuVariables.selectedChannel].Frequency, true, false);
		break;
	case _BTN_DISPLAY_4:	//AMPLITUDE
		selectedParameter = e_PARAMETER_AMPLITUDE;
		GP_ResetTypingScreen(&DDS_Variables[menuVariables.selectedChannel].Amplitude, true, false);
		break;
	case _BTN_DISPLAY_5:	//PHASE OFFSET
		selectedParameter = e_PARAMETER_DC_OFFSET;
		GP_ResetTypingScreen(&DDS_Variables[menuVariables.selectedChannel].DCOffset, true, false);
		break;
	}
}


static void btn_encoder(uint8_t btnEncoder, int8_t encoder){
	menu_ProcessEncoder(btnEncoder, encoder);
}


static void btn_keypad(uint8_t KeyPressed){
	menu_ProcessKeypadPress(KeyPressed);
}

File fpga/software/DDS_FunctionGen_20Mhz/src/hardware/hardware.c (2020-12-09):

/*
 * hardwere.c
 *
 *  Created on: 27 gen 2018
 *      Author: Manuel
 */

#include "../lcd/GLCD.h"
#include "hardware.h"
#include "../definitions.h"
#include "../data_structures/dataStructures.h"
#include "../sd_card/wavPlayer.h"
#include <stdint.h>
#include <system.h>
#include <altera_avalon_pio_regs.h>
#include <sys/alt_irq.h>
#include <math.h>
#include <stdio.h>

//Global variables
volatile uint8_t keypad 	= 0x00;
volatile uint8_t btnDisplay = 0x00;
volatile uint8_t btnEncoder = 0x00;
volatile int8_t	 encoder 	= 0;
volatile bool 	 resetDDS 	= true;

//Function declaration
static uint32_t ComputePhaseStep(s_EditableValue* editableValue);
static uint16_t ComputeAmplitude(s_EditableValue* editableValue, bool impedance50Ohm);
static uint32_t ComputePhaseOffset(s_EditableValue* phaseOffset);
static uint16_t ComputeAmplitudeOffset(s_EditableValue* amplitudeOffset);
static uint16_t ComputeModIndex(s_EditableValue* modulationIndex);
static void ResetDDSModules();
static void ISR_Keypad(void* context);
static void ISR_btnDisplay(void* context);
static void ISR_btnEncoder(void* context);
static void ISR_btnEnable(void* context);
static void ISR_lookupRam(void* context);

//Updates the variables onto the fpga
void updateVariablesOnFpga(){
	//DDS0
	IOWR_ALTERA_AVALON_PIO_DATA(DDS0_PHASESTEP_BASE, 		ComputePhaseStep(&DDS_Variables[0].Frequency));
	IOWR_ALTERA_AVALON_PIO_DATA(DDS0_PHASEOFFSET_BASE, 		ComputePhaseOffset(&DDS_Variables[0].PhaseOffset));
	IOWR_ALTERA_AVALON_PIO_DATA(DDS0_PWM_AMPLITUDE_BASE,	ComputeAmplitude(&DDS_Variables[0].Amplitude, DDS_Variables[0].OutputEmpedance.selected == 0));
	IOWR_ALTERA_AVALON_PIO_DATA(DDS0_PWM_OFFSET_BASE, 		ComputeAmplitudeOffset(&DDS_Variables[0].DCOffset));
	IOWR_ALTERA_AVALON_PIO_DATA(DDS0_OUTPUTRELAY_BASE, 		DDS_Variables[0].OutputRelay);

	uint16_t DDS0_AM_ModIndex 	= ComputeModIndex(&DDS_Variables[0].AM_ModulationIndex);
	DDS0_AM_ModIndex = (DDS_Variables[0].AM_ModulationON) ? DDS0_AM_ModIndex : 0;
	IOWR_ALTERA_AVALON_PIO_DATA(DDS0_AM_MODPHASESTEP_BASE,	ComputePhaseStep(&DDS_Variables[0].AM_ModulationFrequency));
	IOWR_ALTERA_AVALON_PIO_DATA(DDS0_AM_MODINDEX_BASE, DDS0_AM_ModIndex);

	uint32_t DDS0_FM_ModDeviation = ComputePhaseStep(&DDS_Variables[0].FM_FrequencyDeviation);
	DDS0_FM_ModDeviation = (DDS_Variables[0].FM_ModulationON) ? DDS0_FM_ModDeviation : 0;
	IOWR_ALTERA_AVALON_PIO_DATA(DDS0_FM_MODPHASESTEP_BASE, 		ComputePhaseStep(&DDS_Variables[0].FM_ModulationFrequency));
	IOWR_ALTERA_AVALON_PIO_DATA(DDS0_FM_MODDEVIATIONPHASE_BASE, DDS0_FM_ModDeviation);

	uint16_t DDS0_PM_ModIndex = ComputeModIndex(&DDS_Variables[0].PM_ModulationIndex);
	DDS0_PM_ModIndex = (DDS_Variables[0].PM_ModulationON)  ? DDS0_PM_ModIndex : 0;
	IOWR_ALTERA_AVALON_PIO_DATA(DDS0_PM_MODPHASESTEP_BASE,	ComputePhaseStep(&DDS_Variables[0].PM_ModulationFrequency));
	IOWR_ALTERA_AVALON_PIO_DATA(DDS0_PM_MODINDEX_BASE, DDS0_PM_ModIndex);

	//DDS1
	IOWR_ALTERA_AVALON_PIO_DATA(DDS1_PHASESTEP_BASE, 		ComputePhaseStep(&DDS_Variables[1].Frequency));
	IOWR_ALTERA_AVALON_PIO_DATA(DDS1_PHASEOFFSET_BASE, 	 	ComputePhaseOffset(&DDS_Variables[1].PhaseOffset));
	IOWR_ALTERA_AVALON_PIO_DATA(DDS1_PWM_AMPLITUDE_BASE,	ComputeAmplitude(&DDS_Variables[1].Amplitude, DDS_Variables[1].OutputEmpedance.selected == 0));
	IOWR_ALTERA_AVALON_PIO_DATA(DDS1_PWM_OFFSET_BASE, 		ComputeAmplitudeOffset(&DDS_Variables[1].DCOffset));
	IOWR_ALTERA_AVALON_PIO_DATA(DDS1_OUTPUTRELAY_BASE, 		DDS_Variables[1].OutputRelay);

	uint16_t DDS1_AM_ModIndex = ComputeModIndex(&DDS_Variables[1].AM_ModulationIndex);
	DDS1_AM_ModIndex = (DDS_Variables[1].AM_ModulationON) ? DDS1_AM_ModIndex : 0;
	IOWR_ALTERA_AVALON_PIO_DATA(DDS1_AM_MODPHASESTEP_BASE,	ComputePhaseStep(&DDS_Variables[1].AM_ModulationFrequency));
	IOWR_ALTERA_AVALON_PIO_DATA(DDS1_AM_MODINDEX_BASE, 		DDS1_AM_ModIndex);

	uint32_t DDS1_FM_ModDeviation = ComputePhaseStep(&DDS_Variables[1].FM_FrequencyDeviation);
	DDS1_FM_ModDeviation = (DDS_Variables[1].FM_ModulationON) ? DDS1_FM_ModDeviation : 0;
	IOWR_ALTERA_AVALON_PIO_DATA(DDS1_FM_MODPHASESTEP_BASE, 		ComputePhaseStep(&DDS_Variables[1].FM_ModulationFrequency));
	IOWR_ALTERA_AVALON_PIO_DATA(DDS1_FM_MODDEVIATIONPHASE_BASE,	DDS1_FM_ModDeviation);

	uint16_t DDS1_PM_ModIndex = ComputeModIndex(&DDS_Variables[1].PM_ModulationIndex);
	DDS1_PM_ModIndex = (DDS_Variables[1].PM_ModulationON) ? DDS1_PM_ModIndex : 0;
	IOWR_ALTERA_AVALON_PIO_DATA(DDS1_PM_MODPHASESTEP_BASE,	ComputePhaseStep(&DDS_Variables[1].PM_ModulationFrequency));
	IOWR_ALTERA_AVALON_PIO_DATA(DDS1_PM_MODINDEX_BASE, 		DDS1_PM_ModIndex);

	ResetDDSModules();	//Reset DDS modules if needed
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

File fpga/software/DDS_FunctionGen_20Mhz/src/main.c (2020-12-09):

/*
 * main.c
 *
 *  Created on: 27 gen 2018
 *      Author: Manuel
 */

#include <stdio.h>
#include <system.h>
#include <altera_avalon_pio_regs.h>
#include <stdbool.h>
#include <math.h>
#include "delay/delay.h"
#include "hardware/hardware.h"
#include "hardware/ramLookupTables.h"
#include "lcd/GLCD.h"
#include "menu/menu.h"
#include "menu/graphics/menuBitmaps.h"
#include "sd_card/SPI.h"
#include "sd_card/wavPlayer.h"

void WriteToDebugLED(bool b){
	IOWR_ALTERA_AVALON_PIO_DATA(PIO_LED_DEBUG_BASE, b? 1 : 0);
}

void DrawBootScreen(){
	GLCD_SetFont(_FONT_SMALL);
	GLCD_ClrScr();
	GLCD_PrintString(1, 40, "DDS FunctionGen 20MHz");
	GLCD_PrintString(32, 60, "LOADING ...");
	GLCD_SetFont(_FONT_TINY);
	GLCD_PrintString(2, _LCD_HEIGHT - 12, "Software version: 1.0");
	GLCD_Update();//Transfer buffer to screen
}

int main(){
	WriteToDebugLED(false);

	//Initializations
	delay_ms(500);
	GLCD_Initialize(45);
	GLCD_SetBackLight(0x80);
	delay_ms(100);

	InitInterrupts();
	menu_init();
	SPI_Init();
	delay_ms(100);

	//Initialize ram lookup
	DrawBootScreen();	//Draw boot screen
	InitRamLookups();

	while(true){
		//WriteToDebugLED(true);

		menu_draw();
		updateVariablesOnFpga();
		UpdateRamLookups();

		//ram_dds0_update();


		//delay_ms(500);
		//WriteToDebugLED(false);
		//delay_ms(250);
	}

	return 0;
}

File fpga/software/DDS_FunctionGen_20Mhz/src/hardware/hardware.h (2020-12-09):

/*
 * hardwere.h
 *
 *  Created on: 27 gen 2018
 *      Author: Manuel
 */

#include "../definitions.h"
#include "../data_structures/dataStructures.h"
#include <stdint.h>
#include <stdbool.h>

#ifndef SRC_HARDWERE_HARDWERE_H_
#define SRC_HARDWERE_HARDWERE_H_

//External global variables
	extern volatile uint8_t keypad;

#define _BTN_DISPLAY 0b00111111
#define _BTN_DISPLAY_0	(1 << 0)
#define _BTN_DISPLAY_1	(1 << 1)
#define _BTN_DISPLAY_2	(1 << 2)
#define _BTN_DISPLAY_3	(1 << 3)
#define _BTN_DISPLAY_4	(1 << 4)
#define _BTN_DISPLAY_5	(1 << 5)
	extern volatile uint8_t btnDisplay;

#define _BTN_ENCODER 0b00011001
#define _BTN_ENCODER_PB	(1 << 0)
#define _ENCODER_1		(1 << 1)
#define _ENCODER_0		(1 << 2)
#define _BTN_ENCODER_R	(1 << 3)
#define _BTN_ENCODER_L	(1 << 4)
	extern volatile uint8_t btnEncoder;
	extern volatile int8_t	encoder;

#define _BTN_ENABLE_0	(1 << 0)
#define _BTN_ENABLE_1	(1 << 1)

	extern volatile bool	resetDDS;	//If set to true the DDS module is reseted (resets the phase difference between channels)

//Functions
	void InitInterrupts();			//Funzione che inizializza gli interrupt
	void updateVariablesOnFpga();	//Funzione che aggiorna i registri della fpga

#endif /* SRC_HARDWERE_HARDWERE_H_ */
